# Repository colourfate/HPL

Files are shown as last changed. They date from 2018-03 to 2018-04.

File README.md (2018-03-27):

---

---

<h1 id="building">building</h1>
<h2 id="特性">特性</h2>
<ol>
<li>使用<a href="https://www.ai-thinker.com/">安信可</a>A9G模块开发的GPS定位器，基本功能是进行定位，然后将定位信息上传到服务器。</li>
<li>使用GPS组合导航技术，将惯性导航信息和GPS定位信息进行融合，得到较高精度的定位信息。</li>
<li>模块充电接口为micro USB接口，并且集成锂电池充电功能，不需使用专门的充电器，只需插上USB接口即可充电。</li>
<li>模块具备USB供电和电池供电自动切换功能，当插入USB电源后，模块将自动从USB接口进行取电，同时对电池进行充电；断开USB电源，模块从电池进行取电。</li>
</ol>
<h2 id="使用方法">使用方法</h2>
<ol>
<li>软件部分使用<a href="https://github.com/Ai-Thinker-Open/GPRS_C_SDK">安信可的SDK</a>进行开发。</li>
<li>PCB图使用Altium Designer绘制，提供原理图和PCB图。</li>
</ol>
<h2 id="更改记录">更改记录</h2>
<ol>
<li>增加惯性导航传感器，能够获取当前模块的姿态、朝向、加速度等信息。</li>
<li>定位和网络通信改为A9G模块，取消了单片机，简化了电路复杂度，电路板尺寸缩小到5*3.2cm。</li>
<li>增加锂电池充电管理芯片。</li>
<li>增加供电自动切换电路。</li>
<li>调整开关、SIM卡插槽和USB接口位置，使其朝向一致。</li>
</ol>

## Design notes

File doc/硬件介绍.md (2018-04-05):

---

---

<h1 id="硬件介绍">硬件介绍</h1>
<h2 id="概述">概述</h2>
<ol>
<li>能够使用GPS/BD进行定位，然后通过网络将定位信息上传到服务器。</li>
<li>无单片机，简化了电路复杂度，电路板尺寸缩小。</li>
<li>集成锂电池自动充电功能，充电接口为micro USB，不需使用专门的充电器，只需插上USB接口即可充电。</li>
<li>模块具备USB供电和电池供电自动切换功能，当插入USB电源后，模块将自动从USB接口进行取电，同时对电池进行充电；断开USB电源，模块从电池进行取电。</li>
</ol>
<h2 id="特性">特性</h2>
<h3 id="控制芯片">1. 控制芯片</h3>
<p>控制芯片主要完成GPS信号的接收和网络通信功能。同时需要控制LED灯和对电池电量进行监控。<br>
控制芯片</p>
<ul>
<li>32位内核，主频高达312MHz，4k指令缓存，4k数据缓存</li>
<li>多达29个GPIO（两个GPIO作为下载口）</li>
<li>实时时钟、闹钟</li>
<li>1个USB1.1接口</li>
<li>2个带流控的UART接口（+1个下载调试串口）</li>
<li>2个SPI接口</li>
<li>3个I2C接-   1个SDMMC控制器（接口）</li>
<li>2个10位ADC接口</li>
<li>32Mb(4MB) SPI NOR Flash</li>
<li>32Mb(4MB) DDR PSRAM</li>
<li>8kHz、13Bits/sample ADC mic</li>
<li>48kHz、16bits/sample DAC Audio</li>
<li>四频GSM/GPRS（800/900/1800/1900MHz)</li>
<li>语音通话</li>
<li>短信服务</li>
</ul>
<h3 id="电源管理">2. 电源管理</h3>
<p>由于控制芯片在向服务器发送数据的瞬间需要较高的电流，该电流值可能达到2A。因此这里使用了SY8089开关稳压芯片，能够在提供大电流的同时保证90%以上的转换效率。<br>
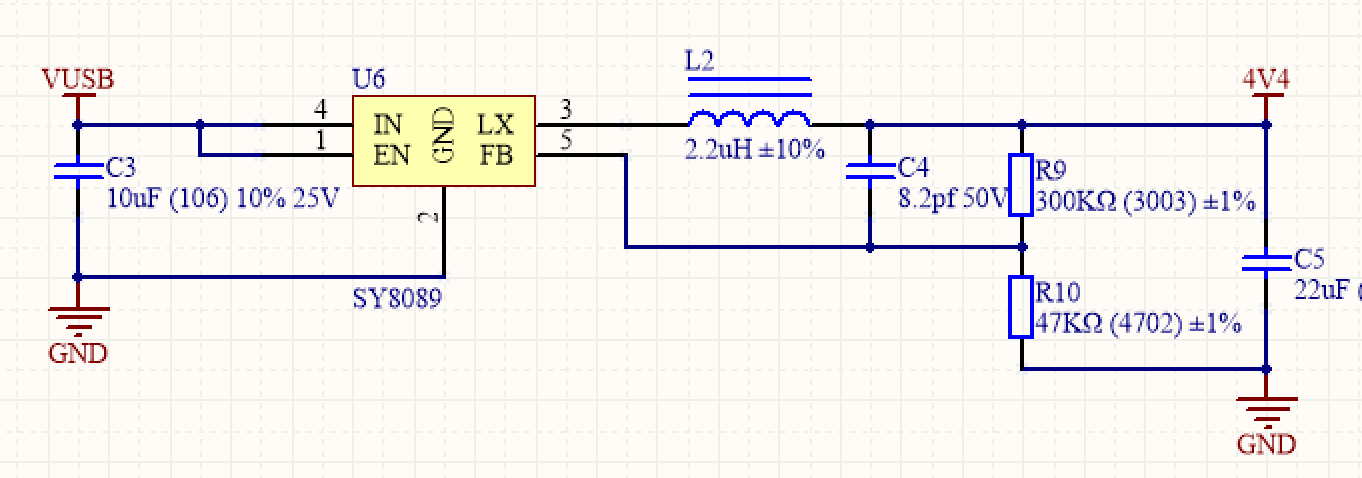
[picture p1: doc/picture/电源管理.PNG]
电源管理
</p>
<ul>
<li>低至80mΩ的导通电阻</li>
<li>2.7~5.5V宽输入电压</li>
<li>2A持续电流，3A峰值电流</li>
<li>1MHz开关频率最大限度地减少了外部元件</li>
<li>内部软启动，对浪涌电流进行很好的限制</li>
<li>可靠的短路保护和过压保护</li>
<li>采用SOT23-5小型封装</li>
</ul>
<h3 id="充电管理">3. 充电管理</h3>
<p>定位器集成了锂电池充电管理功能，只需插入USB接口提供5V电压即可充电。充电部分使用TP4054芯片进行管理，该芯片具有完整的单节锂离子电池采用恒定电流/恒定电压线性充电功能，其 SOT 封装与较少的外部元件数目使得该芯片非常适合在便携设备中的应用。<br>
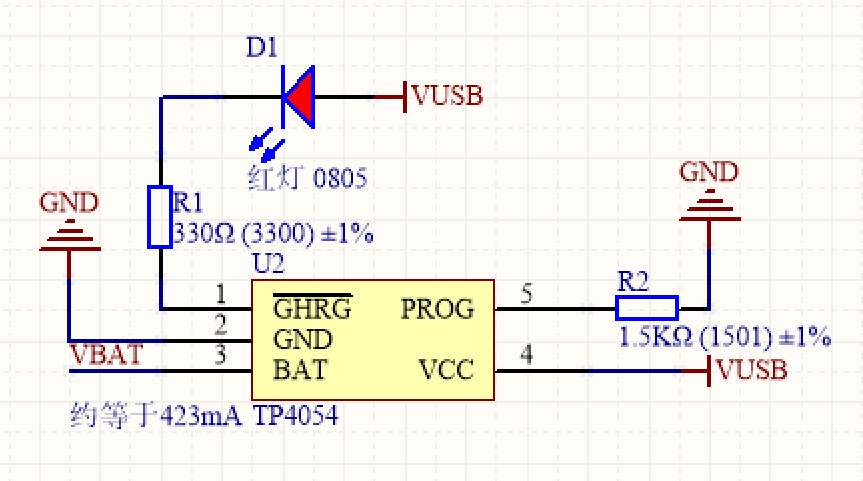
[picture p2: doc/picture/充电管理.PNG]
充电管理
</p>
<ul>
<li>高达 800mA 的可编程充电电流</li>
<li>无需 MOSFET、检测电阻器或隔离二极管</li>
<li>用于单节锂离子电池、采用 SOT23-5 封装的完 整线性充电器</li>
<li>恒定电流/恒定电压操作，并具有可在无过热危 险的情况下实 现充电速率最大化的热调节功能</li>
<li>直接从 USB 端口给单节锂离子电池充电</li>
<li>精度达到±1%的 4.2V 预设充电电压</li>
<li>用于电池电量检测的充电电流监控器输出</li>
<li>自动再充电</li>
<li>充电状态输出引脚</li>
<li>C/10 充电终止</li>
<li>待机模式下的供电电流为 45uA</li>
<li>2.9V涓流充电器件版ᴀ</li>
<li>软启动限制了浪涌电流</li>
<li>采用 5 引脚 SOT-23 封装。</li>
</ul>
<h3 id="供电自动切换">4. 供电自动切换</h3>
<p>定位器自带锂电池，并且具有锂电池充电功能。因此在锂电池充电的同时打开定位器就会出现电池边充边放的情形，这会对锂电池的寿命造成损害。为了避免这种情况发生，该定位器加入了供电自动切换功能。<br>
当插入USB电源后，模块将锂电池的供电断开，使用切换到USB进行供电，同时USB对电池进行充电；拔出USB接口，锂电池重新被接入供电电路，模块从电池进行取电。<br>
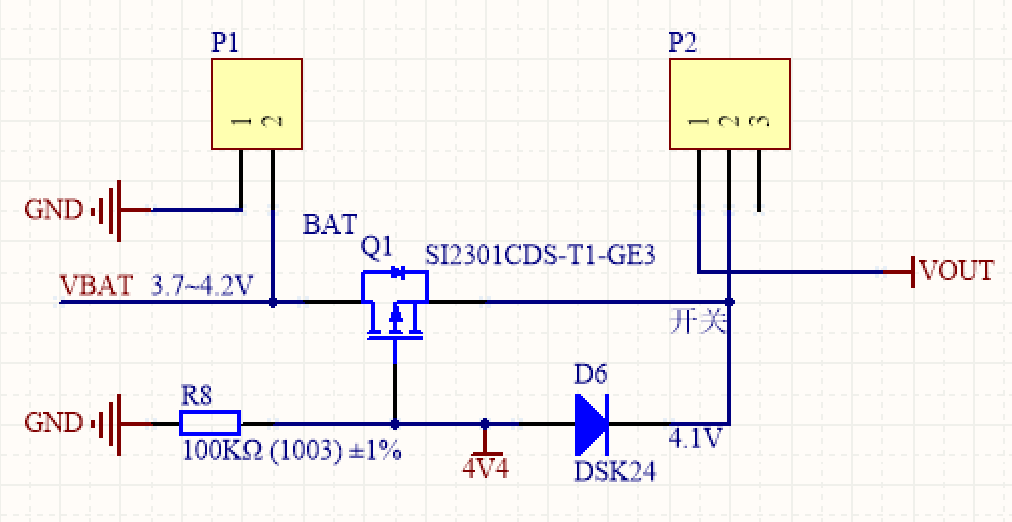
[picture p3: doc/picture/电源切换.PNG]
电源切换
</p>
<h3 id="电量监控">5. 电量监控</h3>
<p>控制芯片能使用ADC对电池电压进行采集，从而判断当前电池电量。当电池电量过低时进行报警。<br>
电源切换</p>

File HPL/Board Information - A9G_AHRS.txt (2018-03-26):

Board Information Report
Filename     : D:\Workspace\AD\Project\HPL\A9G_AHRS.PcbDoc
Date         : 2018/3/22
Time         : 9:34:43
Time Elapsed : 00:00:00

Routing Information
    Routing completion, 100.00%
    Connections, 88
    Connections routed, 88
    Connections remaining, 0
count : 4

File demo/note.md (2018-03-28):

### 介绍
这是JY901的测试程序，通过i2c接口和JY901通信，这里主要实现对加速度、角速度、磁场、角度和四元数的读取。
### 使用方法
放入demo文件夹中，使用指令`./build.sh demo JY901`即可编译生成hex文件。

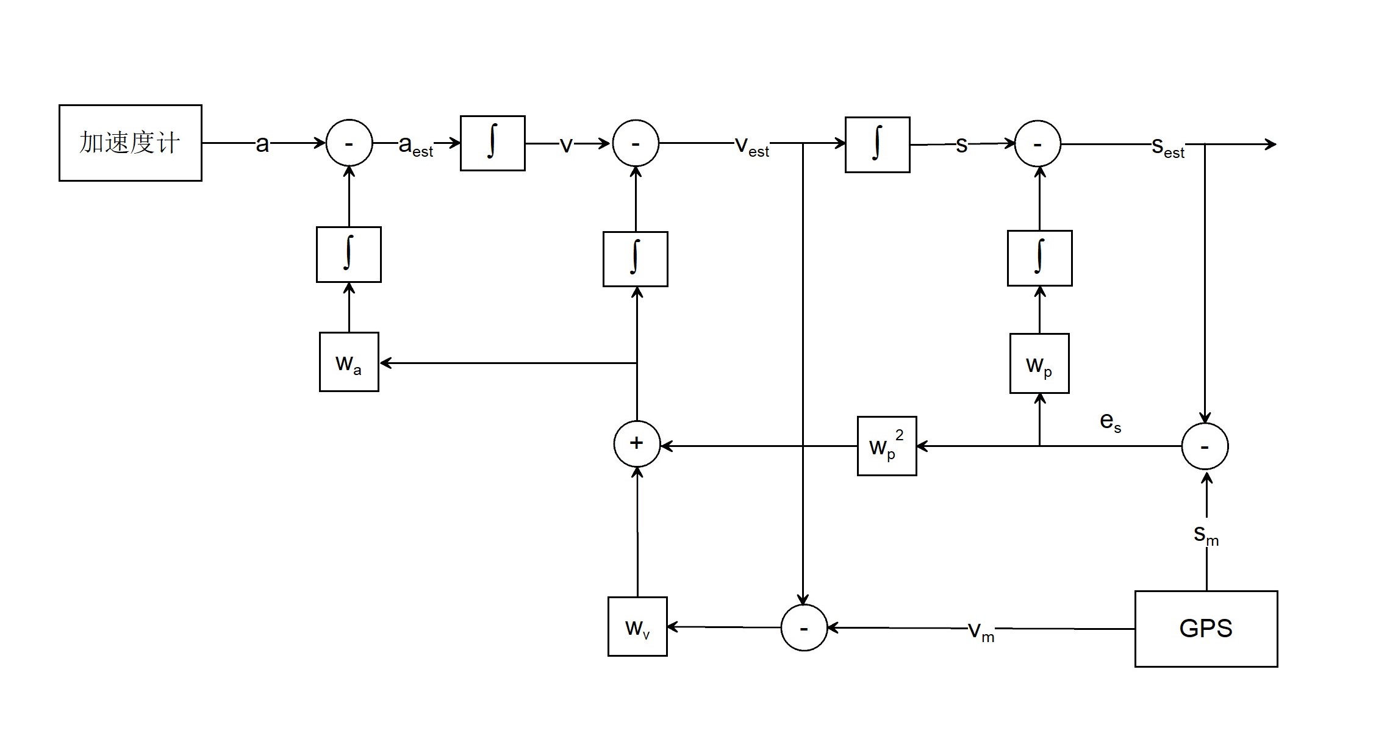
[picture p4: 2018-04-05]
doc/picture/theory.jpg

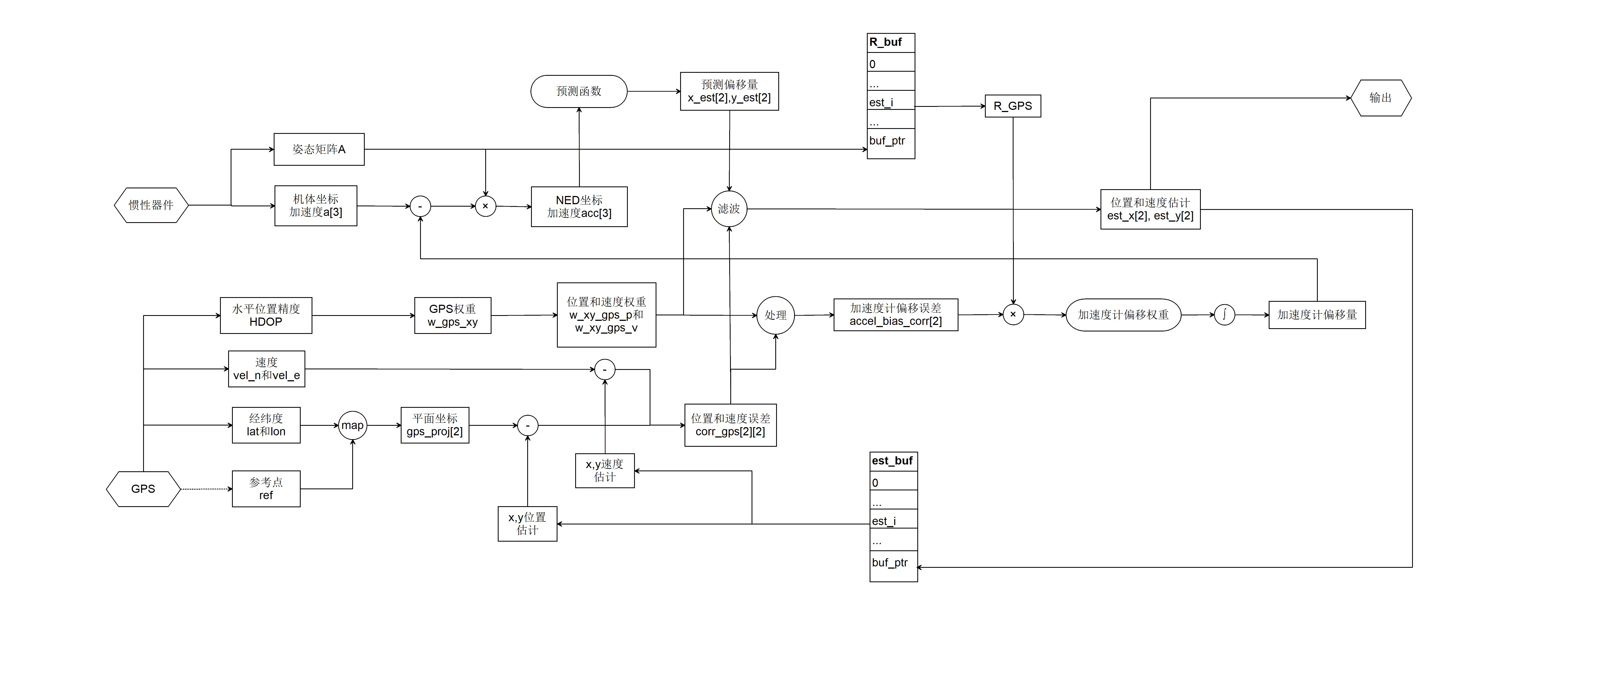
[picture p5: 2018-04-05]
doc/picture/position_estimation.jpg

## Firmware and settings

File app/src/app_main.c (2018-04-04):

#include <string.h>
#include <stdio.h>
#include <time.h>

#include <api_os.h>
#include <api_gps.h>
#include <api_event.h>
#include <api_hal_uart.h>
#include <api_debug.h>
#include <api_socket.h>
#include <api_network.h>
#include <api_hal_i2c.h>

#include "buffer.h"
#include "gps_parse.h"
#include "integrated_nav.h"
#include "JY901_i2c.h"
#include "led.h"
#include "socket.h"

/*********************************************************************/
// GPS
#define GPS_DATA_BUFFER_MAX_LENGTH 2048

Buffer_t gpsNmeaBuffer;
uint8_t  gpsDataBuffer[GPS_DATA_BUFFER_MAX_LENGTH];
uint8_t tmp[1024];

/****************************** APP ***********************************/
// APP
#define MAIN_TASK_STACK_SIZE    (2048 * 2)
#define MAIN_TASK_PRIORITY      1
#define MAIN_TASK_NAME          "Send GPS to server"

static HANDLE mainTaskHandle = NULL;

bool gps_ready = false;
bool conn_status = false;

/**********************************************************************/

void GpsUpdate()
{
    int32_t index = Buffer_Query(&gpsNmeaBuffer,"$GNVTG",strlen("$GNVTG"),Buffer_StartPostion(&gpsNmeaBuffer));
    if(index >= 0)
    {
        // Trace(1,"find $GNVTG");
        index = Buffer_Query(&gpsNmeaBuffer,"\r\n",strlen("\r\n"),index);
        if(index >= 0)
        {
            Trace(1,"find complete GPS frame");
            
            memset(tmp,0,sizeof(tmp));
            uint32_t len = Buffer_Size2(&gpsNmeaBuffer,index)+1;
            Trace(1,"frame len:%d",len);
            if(!Buffer_Gets(&gpsNmeaBuffer,tmp,len))
            {
                Trace(1,"get data from buffer fail");
                return;
            }
            GPS_Parse(tmp);
			gps_ready = true;
			Trace(1, "clock=%d", (int)(clock() / CLOCKS_PER_MSEC));
        }
    }
}


void EventDispatch(API_Event_t* pEvent)
{
	static uint8_t flag = 0; // GPS
    switch(pEvent->id)
    {	
		// socket event
        case API_EVENT_ID_NO_SIMCARD:
            Trace(10,"!!NO SIM CARD%d!!!!",pEvent->param1);
            break;

        case API_EVENT_ID_NETWORK_REGISTERED_HOME:
        case API_EVENT_ID_NETWORK_REGISTERED_ROAMING:
            Trace(2,"network register success");
			// the GPS may cause the two events
			if(socketFd == -1){
				Network_StartAttach();
			}
			flag = 1;
            break;

        case API_EVENT_ID_NETWORK_ATTACHED:
            Trace(2,"network attach success");
            Network_PDP_Context_t context = {
                .apn        ="cmnet",
                .userName   = ""    ,
                .userPasswd = ""
            };
            Network_StartActive(context);
            break;

        case API_EVENT_ID_NETWORK_ACTIVATED:
            Trace(2,"network activate success");
            sem = 1;
            break;

        case API_EVENT_ID_SOCKET_CONNECTED:
			conn_status = true;
            sem = 1;
            break;
        case API_EVENT_ID_SOCKET_SENT:
        {
            sem = 1;
            break;
        }
        case API_EVENT_ID_SOCKET_RECEIVED:
        {
            int fd = pEvent->param1;
            int length = pEvent->param2>RECEIVE_BUFFER_MAX_LENGTH?RECEIVE_BUFFER_MAX_LENGTH:pEvent->param2;
            memset(buffer,0,sizeof(buffer));
            length = Socket_TcpipRead(fd,buffer,length);
            Trace(2,"socket %d received %d bytes data:%s",fd,length,buffer);
            break;
        }
        case API_EVENT_ID_SOCKET_CLOSED:
        {
            int fd = pEvent->param1;
            Trace(2,"socket %d closed",fd);
            sem = 1;
			conn_status = false;
            break;
        }
        case API_EVENT_ID_SOCKET_ERROR:
        {
            int fd = pEvent->param1;
            Trace(2,"socket %d error occurred,cause:%d",fd,pEvent->param2);
            errorCode = pEvent->param2;
            sem = 1;
			conn_status = false;
            break;
        }
		// GPS event
		case API_EVENT_ID_GPS_UART_RECEIVED:
            // Trace(1,"received GPS data,length:%d, data:%s,flag:%d",pEvent->param1,pEvent->pParam1,flag);
            if(flag)
            {
                Buffer_Puts(&gpsNmeaBuffer,pEvent->pParam1,pEvent->param1);
                GpsUpdate();
            }
            break;
        case API_EVENT_ID_UART_RECEIVED:
            if(pEvent->param1 == UART1)
            {
                uint8_t data[pEvent->param2+1];
                data[pEvent->param2] = 0;
                memcpy(data,pEvent->pParam1,pEvent->param2);
                Trace(1,"uart received data,length:%d,data:%s",pEvent->param2,data);
            }
            break;
		
        default:
            break;
    }
}

/*
#define SLEEP_TASK_STACK_SIZE (1024*10)
#define SLEEP_TASK_PRIORITY	(0)
#define SLEEP_TASK_NAME	"sleep"

void sleep_testTask(void *pData)
{
	while(1){
		Trace(3, "10");
		OS_Sleep(50);
	}
}
*/

void app_MainTask(void *pData)
{
	API_Event_t* event=NULL;

	/**************************************************************/
	// init socket
	CreateSem(&sem);
    OS_CreateTask(socketTestTask,
        NULL, NULL, SOCKET_TASK_STACK_SIZE, SOCKET_TASK_PRIORITY, 0, 0, SOCKET_TASK_NAME);
	/**************************************************************/
	// init GPS
    GPS_Open(NULL);
    Buffer_Init(&gpsNmeaBuffer,gpsDataBuffer,GPS_DATA_BUFFER_MAX_LENGTH);
	/**************************************************************/
	// init i2c
	I2C_Config_t config;
    config.freq = I2C_FREQ_100K;
    I2C_Init(I2C_JY901, config);
	// start position estimation
	OS_CreateTask(position_estimator_testTask,
           NULL, NULL, INAV_TASK_STACK_SIZE, INAV_TASK_PRIORITY, 0, 0, INAV_TASK_NAME);
	//OS_CreateTask(sleep_testTask,
    //       NULL, NULL, SLEEP_TASK_STACK_SIZE, SLEEP_TASK_PRIORITY, 0, 0, SLEEP_TASK_NAME);
	/***************************************************************/
	// start led task
	OS_CreateTask(led_testTask,
            NULL, NULL, LED_TASK_STACK_SIZE, LED_TASK_PRIORITY, 0, 0, LED_TASK_NAME);
	// handle event
    while(1)
    {
        if(OS_WaitEvent(mainTaskHandle, (void**)&event, OS_TIME_OUT_WAIT_FOREVER))
        {
            EventDispatch(event);
            OS_Free(event->pParam1);
            OS_Free(event->pParam2);
            OS_Free(event);
        }
    }
}



// The name of entry fun must be 'xxx_MainTask', the 'xxx' is fold name
void app_Main(void)
{
	mainTaskHandle = OS_CreateTask(app_MainTask,
        NULL, NULL, MAIN_TASK_STACK_SIZE, MAIN_TASK_PRIORITY, 0, 0, MAIN_TASK_NAME);
	// Listen the event of Task. A Main fun has only a Handle, named UserHandle
    OS_SetUserMainHandle(&mainTaskHandle);
}

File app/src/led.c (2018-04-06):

#include <api_hal_gpio.h>
#include <stdbool.h>
#include <api_debug.h>
#include <api_os.h>
#include <api_hal_pm.h>
#include <api_socket.h>
#include <stdio.h>
#include <api_hal_adc.h>

#include "led.h"
#include "integrated_nav.h"
#include "mymath.h"

extern struct location_position local_pos;
extern bool conn_status;

void led_testTask()
{
	GPIO_config_t led_gps = {
        .mode         = GPIO_MODE_OUTPUT,
		.pin = GPIO_PIN27,
        .defaultLevel = GPIO_LEVEL_LOW
    };
	GPIO_config_t led_net = {
        .mode         = GPIO_MODE_OUTPUT,
		.pin = GPIO_PIN28,
        .defaultLevel = GPIO_LEVEL_LOW
    };
	// open GPIO power
	PM_PowerEnable(POWER_TYPE_VPAD, true);
	// init GPIO27 and 28
	GPIO_Init(led_gps);
	GPIO_Init(led_net);
	// blink led when start up
	GPIO_SetLevel(led_gps, GPIO_LEVEL_HIGH);
	GPIO_SetLevel(led_net, GPIO_LEVEL_HIGH);
	OS_Sleep(1000);
	GPIO_SetLevel(led_gps, GPIO_LEVEL_LOW);
	GPIO_SetLevel(led_net, GPIO_LEVEL_LOW);

	// ADC
	uint16_t value = 0, mV = 0;
    ADC_Config_t config = {
        .channel = ADC_CHANNEL_0,
        .samplePeriod = ADC_SAMPLE_PERIOD_100MS
    };
    ADC_Init(config);
	bool low_power = false;

	while(1){
		
		if(!ADC_Read(ADC_CHANNEL_0, &value, &mV)){
			Trace(1, "ADC0 cannot read");
		}else{
			if(mV*3<3700){
				low_power = true;
			}else{
				low_power = false;
			}
		}
		if(low_power){
			GPIO_SetLevel(led_gps, GPIO_LEVEL_HIGH);
			GPIO_SetLevel(led_net, GPIO_LEVEL_HIGH);
			OS_Sleep(2000);
			GPIO_SetLevel(led_gps, GPIO_LEVEL_LOW);
			GPIO_SetLevel(led_net, GPIO_LEVEL_LOW);
		}else{
			if(local_pos.gps_valid){
				GPIO_SetLevel(led_gps, GPIO_LEVEL_HIGH);
				OS_Sleep(150);
				GPIO_SetLevel(led_gps, GPIO_LEVEL_LOW);
			}
			if(conn_status){
				GPIO_SetLevel(led_net, GPIO_LEVEL_HIGH);
			}else{
				GPIO_SetLevel(led_net, GPIO_LEVEL_LOW);
			}
		}
		OS_Sleep(2000);
	}
}

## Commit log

2018-03-27 JY901 i2c driver
2018-04-02 complete position estimator
    some bug in the reproject function
    [app_main.c, led.c]
2018-04-02 chip document
    [A9G-dev_V1.2.SCHLIB]
2018-04-04 complete socket upload
2018-04-06 Fixed a unit conversion bug
    some problem in positon estimation
    [led.c]
